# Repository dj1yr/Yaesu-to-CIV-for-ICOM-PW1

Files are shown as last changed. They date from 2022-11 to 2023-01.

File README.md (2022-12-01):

The code is alpha, please note!

This small project translates the BCD code from Yaesu to ICOM CIV for communication with the PW1.

What do you have to do to make the PW1 work? First you have to teach the PW1 the address, this is in the manual, only with this solution you have to change the band until the LED on the remote is permanently on.

Now you have to know how the PW1 checks if the right subscriber can be reached, I will try to explain that.

When the PW1 is switched on and a participant has been programmed, the PW1 sends 6 bytes consisting of 0xFE,0xFE, address of participant, address PW1, 0x03,0xFD. The PW1 uses different data rates, from 0k6, 1k2, 2k4, 4k8, 9k6 and 19k2, at each data rate the query byte is sent 2x, the TRX must respond within 20ms, if not the next data rate is used, this is repeated 3x. If the TRX does not answer, the CIV communication is stopped, this can be retriggered by switching between TRX1 and TRX2 on the remote control, then the loop is restarted.

Now let's assume that the first communication worked, the first response from the TRX is structured as follows, 0xFE, 0xFE , address PW1, address TRX, 0x00 or 0x03, frequency data, 0xFD, then the PW1 switches to the received band.

Now the PW1 sends a new request every 10s, the CMD byte is initially 0x03, when the corresponding response comes, the PW1 sends 0x04, i.e. request for modulation. If one does not react to this, it can happen that the connection to the PW1 is interrupted, this also happened to me from time to time, so I send other answers.

I have developed a small board that fits into a SUBD15 connector housing, on the board an Atmega8 with TQFP32 housing is used, the Atmega 8 can of course be replaced by a pin compatible type.

In the development phase I am working with an Arduino Mega 2560 board.

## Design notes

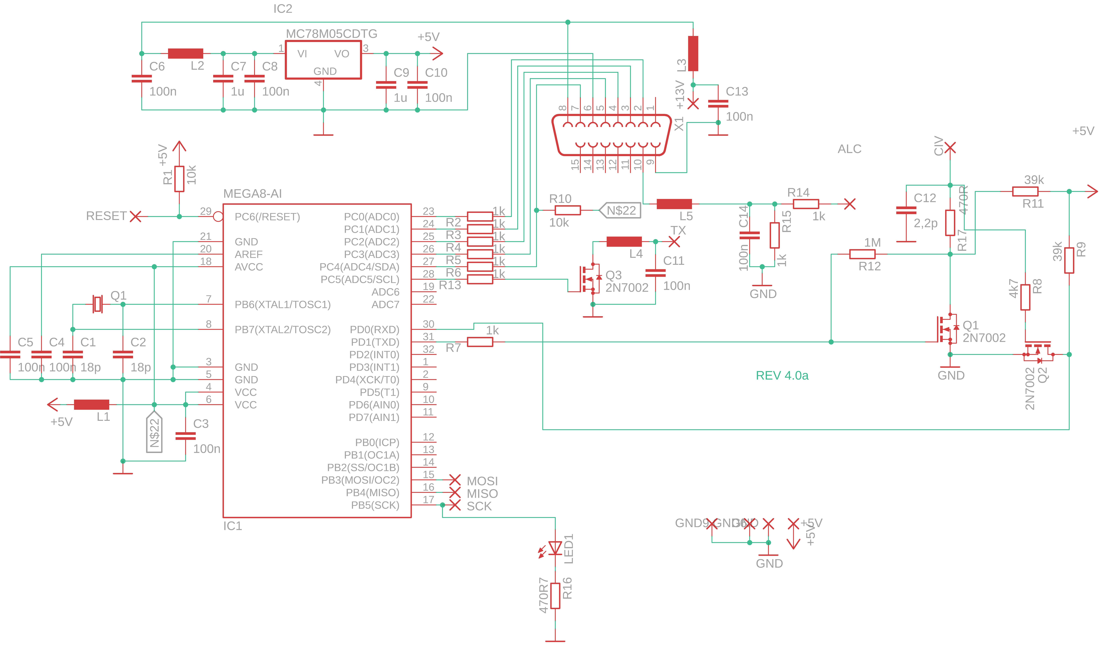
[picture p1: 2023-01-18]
schematic.png

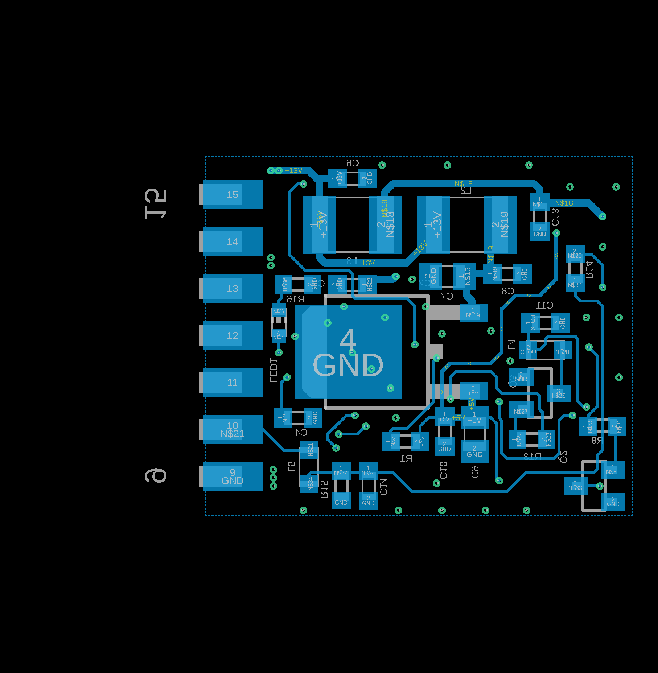
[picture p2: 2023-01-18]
Bottom_brd.png

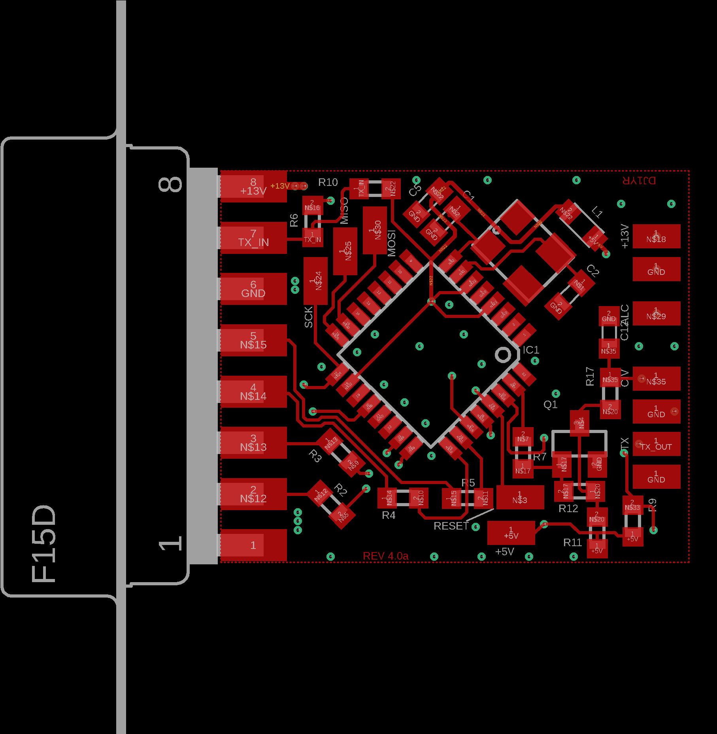
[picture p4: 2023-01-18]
Top_brd.png

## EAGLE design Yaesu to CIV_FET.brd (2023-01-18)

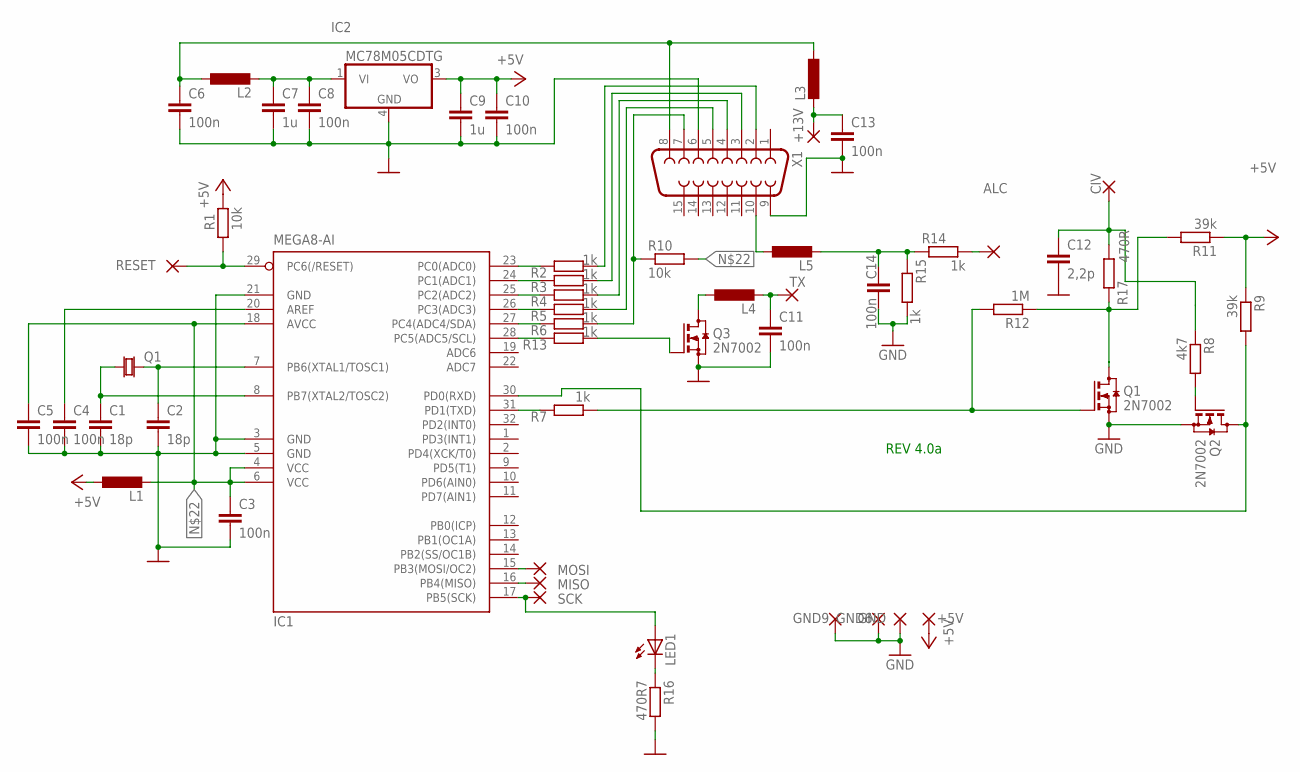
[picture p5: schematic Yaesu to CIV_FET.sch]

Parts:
+5V, +13V: SMD2; SMD1,27-2,54
ALC: SMD2; SMD1,27-2,54
C1, C2: 18p; C0603K
C3, C4, C5, C6, C8, C10, C11, C13, C14: 100n; C0603K
C7, C9: 1u; C0805K
C12: 2,2p; C0603K
CIV: SMD2; SMD1,27-2,54
GND, GND6, GND9: SMD2; SMD1,27-2,54
IC1: MEGA8-AI; TQFP32-08
IC2: MC78M05CDTG; DPACK_3
L1, L4, L5: L-EUL2012C; L2012C
L2, L3: L-EUL1812; L1812
LED1: LEDCHIP-LED0603; CHIP-LED0603
MISO: SMD2; SMD1,27-2,54
MOSI: SMD2; SMD1,27-2,54
Q1, Q2, Q3: 2N7002; SOT23
R1, R10: 10k; R0603
R2, R3, R4, R5, R6, R7, R13, R14, R15: 1k; R0603
R8: 4k7; R0603
R9, R11: 39k; R0603
R12: 1M; R0603
R16: 470R7; R0603
R17: 470R; R0603
RESET: SMD2; SMD1,27-2,54
SCK: SMD2; SMD1,27-2,54
TX: SMD2; SMD1,27-2,54
X1: F15D

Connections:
+5V: +5V.1, C9.1, C10.1, IC2.3 (VO), L1.1, R1.2, R9.1, R11.1
+13V: C6.1, L2.1, L3.1, X1.8
GND: C1.2, C2.2, C3.2, C4.2, C5.2, C6.2, C7.2, C8.2, C9.2, C10.2, C11.2, C12.2, C13.2, C14.2, GND.1, GND6.1, GND9.1, IC1.3 (GND), IC1.5 (GND), IC1.21 (GND), IC2.4 (GND), Q1.2 (S), Q2.2 (S), Q3.2 (S), R15.2, R16.2, X1.6, X1.9
unnamed: C2.1, IC1.7 (PB6(XTAL1/TOSC1))
unnamed: C1.1, IC1.8 (PB7(XTAL2/TOSC2))
unnamed: IC1.29 (PC6(/RESET)), R1.1, RESET.1
unnamed: IC1.23 (PC0(ADC0)), R2.2
unnamed: IC1.31 (PD1(TXD)), R7.2
unnamed: C4.1, IC1.20 (AREF)
unnamed: IC1.24 (PC1(ADC1)), R3.2
unnamed: IC1.25 (PC2(ADC2)), R4.2
unnamed: IC1.26 (PC3(ADC3)), R5.2
unnamed: R2.1, X1.2
unnamed: R3.1, X1.3
unnamed: R4.1, X1.4
unnamed: R5.1, X1.5
unnamed: IC1.27 (PC4(ADC4/SDA)), R6.2
unnamed: Q1.1 (G), R7.1, R12.2
unnamed: +13V.1, C13.1, L3.2
unnamed: C7.1, C8.1, IC2.1 (VI), L2.2
unnamed: R11.2, R12.1, R17.2
unnamed: L5.1, X1.10
unnamed: C3.1, C5.1, IC1.4 (VCC), IC1.6 (VCC), IC1.18 (AVCC), L1.2, R10.2
unnamed: IC1.28 (PC5(ADC5/SCL)), R13.2
unnamed: IC1.17 (PB5(SCK)), LED1.A, SCK.1
unnamed: IC1.16 (PB4(MISO)), MISO.1
unnamed: Q3.1 (G), R13.1
unnamed: L4.1, Q3.3 (D)
unnamed: ALC.1, R14.2
unnamed: IC1.15 (PB3(MOSI/OC2)), MOSI.1
unnamed: Q2.1 (G), R8.2
unnamed: IC1.30 (PD0(RXD)), Q2.3 (D), R9.2
unnamed: C14.1, L5.2, R14.1, R15.1
unnamed: C12.1, CIV.1, R8.1, R17.1
unnamed: LED1.C, R16.1
TX_IN: R6.1, R10.1, X1.7
TX_OUT: C11.1, L4.2, TX.1

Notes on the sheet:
REV 4.0a

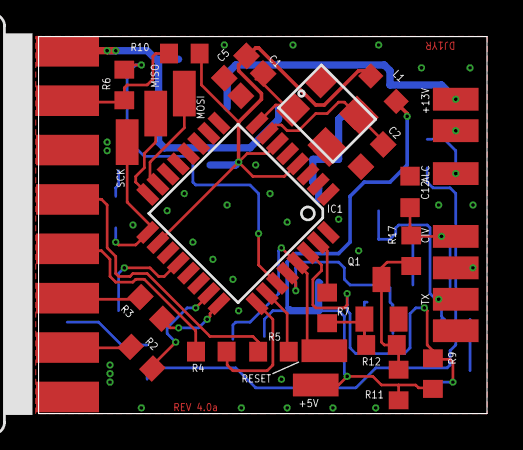
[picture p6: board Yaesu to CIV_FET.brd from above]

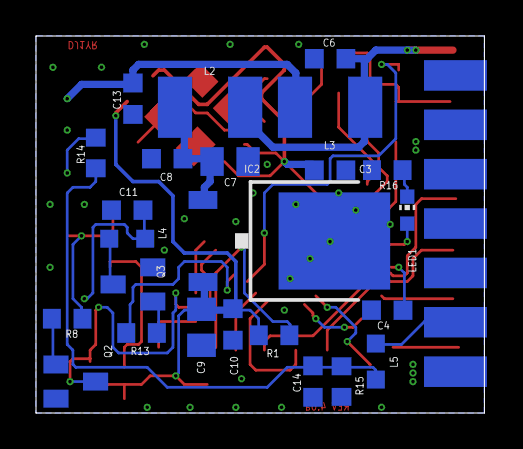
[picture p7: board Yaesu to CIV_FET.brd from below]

Board: 2 copper layers, 24.9 x 20.9 mm, 55 parts (24 on the bottom side), 37 nets.

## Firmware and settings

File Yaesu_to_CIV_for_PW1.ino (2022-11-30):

//Atmega8 config
#define uart Serial
int y_a = 17;
int y_b = 16;
int y_c = 15;
int y_d = 14;
int tx_in = 18;
int tx_out = 19;
int led = 13;             // led for debug



/*// Arduino Mega 2560 config
#define uart Serial1
int y_a = 2;
int y_b = 3;
int y_c = 4;
int y_d = 5;
int tx_in = 6;
int tx_out = 7;
*/


byte band=0;              //actual band from Yaesu TRX
byte band_old=0;
byte data_start[2]={0xFE,0xFE};
  
byte to_addr = 0x54;      // PW1 adress
byte from_addr = 0x30;    //TRX adress, e.g. IC-726 
byte cmd_1 = 0x00;
byte cmd_2 = 0x03;    //frequ. request
byte cmd_3 = 0x04;    //mode request

byte bnd_1 = 0x00;    //100*Mhz
byte bnd_2 = 0x51;    //10*Mhz
byte bnd_3 = 0x00;    //100*khz
byte bnd_4 = 0x00;    //10*khz
byte bnd_5 = 0x00;    //1*khz +100*hz

byte mode = 0x02;     //mode = lsb
byte data_stop = 0xFD;

byte cmd_mode = 0;    //cmd_mode = 0 -> 0x00, 1 -> 0x03, 2 -> 0x04

boolean tx_ok = false;

void setup(){
uart.begin(9600);

pinMode(y_a,INPUT);
pinMode(y_b,INPUT);  
pinMode(y_c,INPUT);
pinMode(y_d,INPUT);
//pinMode(led, OUTPUT);
pinMode(tx_in, INPUT_PULLUP);
pinMode(tx_out,OUTPUT);

}//end of setup  

byte daten_pw1; 
int i;

int buffer_pw1tx[6];               //receive buffer, 6 bytes from PW1 

void loop(){

/*
// Arduino Mega 2560
y_a = digitalRead(2);
y_b = digitalRead(3);
y_c = digitalRead(4);
y_d = digitalRead(5);
tx_in = digitalRead(6);
*/

// Atmega 8
y_a = digitalRead(17);
y_b = digitalRead(16);
y_c = digitalRead(15);
y_d = digitalRead(14);
tx_in = digitalRead(18);


// Yaesu bcd to CIV frequency ->Mhz+100*khz

if (y_a==0 && y_b==0 && y_c==0 && y_d==0){bnd_2=0x51; bnd_3=0x00; tx_ok = false; band=1;}     //no band signals -> select 6m send 51.00Mhz, TX disabled
if (y_a==1 && y_b==0 && y_c==0 && y_d==0){bnd_2=0x01; bnd_3=0x90; tx_ok = true; band=2;}      //160m send 1.90Mhz, TX enabled
if (y_a==0 && y_b==1 && y_c==0 && y_d==0){bnd_2=0x03; bnd_3=0x70; tx_ok = true; band=3;}      //80m send 3.70Mhz, TX enabled
if (y_a==1 && y_b==1 && y_c==0 && y_d==0){bnd_2=0x07; bnd_3=0x10; tx_ok = true; band=4;}      //60m/40m send 7.10Mhz, TX enabled
if (y_a==0 && y_b==0 && y_c==1 && y_d==0){bnd_2=0x10; bnd_3=0x05; tx_ok = true; band=5;}      //30m send 10.05Mhz, TX enabled
if (y_a==1 && y_b==0 && y_c==1 && y_d==0){bnd_2=0x14; bnd_3=0x20; tx_ok = true; band=6;}      //20m send 14.20Mhz, TX enabled
if (y_a==0 && y_b==1 && y_c==1 && y_d==0){bnd_2=0x18; bnd_3=0x06; tx_ok = true; band=7;}      //17m send 18.06Mhz, TX enabled
if (y_a==1 && y_b==1 && y_c==1 && y_d==0){bnd_2=0x21; bnd_3=0x20; tx_ok = true; band=8;}      //15m send 21.20Mhz, TX enabled
if (y_a==0 && y_b==0 && y_c==0 && y_d==1){bnd_2=0x24; bnd_3=0x90; tx_ok = true; band=9;}      //12m send 24.90Mhz, TX enabled
if (y_a==1 && y_b==0 && y_c==0 && y_d==1){bnd_2=0x28; bnd_3=0x50; tx_ok = true; band=10;}     //10m send 25.500Mhz, TX enabled
if (y_a==0 && y_b==1 && y_c==0 && y_d==1){bnd_2=0x51; bnd_3=0x00; tx_ok = true; band=11;}     //6m send 51.00Mhz, TX enabled
if (y_a==1 && y_b==1 && y_c==1 && y_d==1){bnd_2=0x51; bnd_3=0x00; tx_ok = false; band=12;}    // Yaesu 4m band selected, send 51.00Mhz, TX disabled


      if (band_old!=band){
      cmd_mode=0;  
      data_send();
      }
    
      daten_pw1 = uart.read();
      if ((daten_pw1 == 254)){ 
        PA_data_start();
        }
        delay (1);                      // time for buffer to fill
    
      if(tx_in == LOW && tx_ok == true){
      digitalWrite(tx_out,HIGH);
      }
      else{
      digitalWrite(tx_out,LOW);
      }

    
}//end of loop


void PA_data_start(){                                  

  delay(10);
  
    for ( i = 0; i < 6; i++) {                     
      if (uart.available() > 0) {           
        buffer_pw1tx[i] = uart.read();                           
      }
    }
      if ((buffer_pw1tx[1] == from_addr) && ( buffer_pw1tx[2] ==  to_addr)&&(buffer_pw1tx[3] == cmd_2)){    //check wich command is send from PW1 -> frequence request
          cmd_mode=1;        
          data_send();
      }

      if ((buffer_pw1tx[1] == from_addr) && ( buffer_pw1tx[2] ==  to_addr)&&(buffer_pw1tx[3] == cmd_3)){    //check wich command is send from PW1 -> mode request
          cmd_mode=2;        
          data_send();
      }
}// end of void PA_data_start
  
  void data_send(){
        uart.write(data_start,2); //0xFE start of telegram, send 2x 0xFE
         
        if(cmd_mode == 0){
        uart.write(0x00);
        uart.write(from_addr);    //TRX adress   
        //uart.write(cmd_1);     
        uart.write(cmd_2); 
        uart.write(bnd_5);        //1khz+100hz    
        uart.write(bnd_4);        //10khz
        uart.write(bnd_3);        //100khz
        uart.write(bnd_2);        //10Mhz
        uart.write(bnd_1);        //100Mhz                 
        }
        else if (cmd_mode == 1){
        uart.write(to_addr);      //PW1 adress
        uart.write(from_addr);    //TRX adress                  
        uart.write(cmd_2);
        uart.write(bnd_5);        //1khz+100hz    
        uart.write(bnd_4);        //10khz
        uart.write(bnd_3);        //100khz
        uart.write(bnd_2);        //10Mhz
        uart.write(bnd_1);        //100Mhz        
        }
        else{
        uart.write(to_addr);      //PW1 adress
        uart.write(from_addr);    //TRX adress                  
        uart.write(cmd_3);
        uart.write(0x00);
        uart.write(mode);         //mode = lsb        
        }
        uart.write(data_stop);    //0xFD end of telegramm
        band_old=band;    
  }
